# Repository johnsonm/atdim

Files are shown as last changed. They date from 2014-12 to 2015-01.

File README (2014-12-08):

This design for an attiny-based PWM dimmer circuit is licensed under
the CERN OHL as provided in the file cern_ohl_v_1_2.txt

This project requires that you set the open-project library references
to point to a checkout of git@github.com:open-project/kicadlibrary.git
The attiny part included is a variant on the version in the atmel
library with two pins moved for cosmetic purposes.

Options:

P1 may be 0.1" pitch header or screw terminal
Place P2 (ICSP) only if ICSP function desired
Three 4mm mounting holes provided

PHOTOR1 may be a 2-pin 0.1" header to a remote photoresistor
PHOTOR1 and R1 may be omitted if light sensing is not desired

FR1 may be a fusible resistor of an appropriate rating and value
for the load if the circuit is not otherwise protected, or a
jumper if it is sufficiently protected otherwise.

RV1 may be a 0.2" pitch potentiometer, a 0.1" pitch potentiometer,
a 0.1" pitch trim potentiometer, or a 3-conductor 0.1" or 0.2"
pitch connector (header or molex) to a remote potentiometer.
If you are using a 0.1" pitch part, solder the smaller pads first
as the middle pad's through-hole is sized to accomodate the larger
legs on typical 0.2" pitch potentiometers.

R3 is an optional pull-up resistor to ensure that the MOSFET
switches off cleanly at low duty cycle as described in.
https://gasstationwithoutpumps.wordpress.com/2014/07/28/pwm-controller/

D1 is a freewheel transient suppressing diode required only for
inductive loads such as motor control.

ATTINY85-T is any ATTINY*5 through-hole part that can hold your
desired program.

For low-profile applications:
Install ATTINY*5 directly soldered, not in a socket
U1 (7805) installed with bent leads over R2 and R3
Q1 (MOSFET) installed with bent leads over ATTINY*5
Use remote or low-profile potentiometer for RV1

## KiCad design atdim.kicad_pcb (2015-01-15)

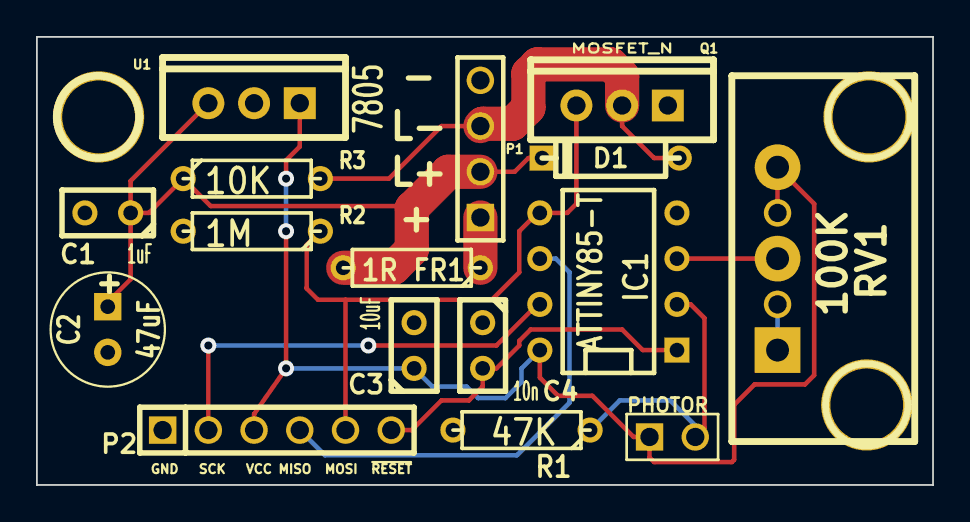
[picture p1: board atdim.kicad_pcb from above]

Board: 2 copper layers, 49.8 x 24.9 mm, 20 parts (0 on the bottom side), 11 nets.

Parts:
1PIN, 1PIN#2, 1PIN#3, 1PIN#4: P***; 1pin
C1: 1uF; C1
C2: 47uF; C1V7
C3: 10uF; C1
C4: 10n; C1
D1: DIODE; D3
FR1: 1R; R3
IC1: ATTINY85-T; DIP-8__300
P1: CONN_4; PIN_ARRAY_4x1
P2: ICSP; PIN_ARRAY-6X1
PHOTOR1: PHOTOR; PIN_ARRAY_2X1
Q1: MOSFET_N; TO220_VERT
R1: 47K; R3
R2: 1M; R3
R3: 10K; R3
RV1: 100K; POTA_Fav
U1: 7805; TO220_VERT

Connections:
+12V: FR1.1, P1.1
/+12VS: C1.1, C2.1, D1.2, FR1.2, P1.2, R3.1, U1.VI
/ADC2: IC1.3, RV1.2
/ADC3: IC1.2, PHOTOR1.2, R1.1
/DRAIN: D1.1, P1.3, Q1.D, R3.2
/MISO: IC1.6, P2.4
/MOSI: IC1.5, P2.5, Q1.G, R2.1
/SCK: IC1.7, P2.2
/VCC: C3.1, IC1.8, P2.3, PHOTOR1.1, RV1.3, U1.VO
/~RESET: C4.2, IC1.1, P2.6
GND: C1.2, C2.2, C3.2, C4.1, IC1.4, P1.4, P2.1, Q1.S, R1.2, R2.2, RV1.1, U1.GND

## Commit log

2014-11-14 Initial version of attiny-based LED PWM dimmer circuit
    [atdim.kicad_pcb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]
2014-11-15 switch to 47K sense resistor for better match for 5549 response
    [atdim.kicad_pcb, atdim.sch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]
2014-11-27 added pull-up resistor, changed some component values
    Added pull-up resistor based on writeup at
    https://gasstationwithoutpumps.wordpress.com/2014/07/28/pwm-controller/
    Modified suggested capacitor values based on additional perusal of
    data sheets for various versions of components.
    Modified suggested R1 value based on experiments with my existing LDRs
    [atdim.kicad_pcb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]
2014-11-27 add annotations on silkscreen for parts and connections
    [atdim.kicad_pcb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]
2014-12-08 mark RESET pin with overbar
    [atdim.kicad_pcb]
2014-12-08 rearrange board: separate power from logic, no need for reverse mounting or folding capacitor leads
    [atdim.kicad_pcb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]
2014-12-08 add a fusible resistor
    [atdim.kicad_pcb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]
2014-12-08 add a freewheel diode just in case I ever want to use this for motor control
    [atdim.kicad_pcb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]
2014-12-08 increase trace width for higher power
    [atdim.kicad_pcb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]
2014-12-10 freewheel diode in schematic
    [atdim.sch]
2015-01-15 reflow ground plane around freewheel diode
    [atdim.kicad_pcb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]
